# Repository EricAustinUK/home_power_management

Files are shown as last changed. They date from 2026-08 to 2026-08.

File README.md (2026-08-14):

# Home Power Management

A bespoke home power management system built on a Raspberry Pi Zero W, optimised by edge AI and written in Rust.
Predicts solar generation with an on-device ML model, then calculates and schedules battery and EV charging around a cheap energy tariff window via Home Assistant. 

## How it works

- **Solar prediction (`ml/`)**: a compact regression model trained on historical weather and solar pv generation data predicts the next 24 hours of solar output. Inference runs locally on the Pi Zero W (ARMv6, 512 MB RAM).
- **Weather input(`software/home_manager/weather_data.rs`)**: hourly forecasts from the OpenMeteo API feed the model.
- **Battery scheduling**: during tariff windows, the expected house load is compared against predicted solar, the battery is configured to charge to cover any shortfall, then reset to its baseline when the tariff ends.
- **EV conditional charging**: reads an EV's battery level, home location, and plug state from Home Assistant to control an IoT enabled charger, switching it off once the target charge (currently 95%) is reached.
- **Control panel (`control_panel.rs`)**: a physical panel (currently on a breadboard) with three "appliance" toggle switches (though only one of these is currently configured, being the one representing the home being inhabited) that feed into the estimate for home energy consumption. Shows the state for each these appliances with an LED. 

## Optimization for ARM

The model and inference path were developed with the Pi Zero W's hardware limitations in mind.

| Metric | Value |
|---|---|
| Model size on disk | 282B |
| Model data size on disk | 99KB |
| Inference latency (Pi Zero W) | 1.51ms |
| RAM footprint | 3664KB |

## Hardware

- Raspberry Pi Zero W
- Custom control panel housing 3 push switches with pull-ups, status LEDs
- Home Assistant instance with battery, EV, and charger integrations

## Setup

1. Clone and copy `.env.example` to `.env`, filling in:
   - `HASS_IP`, `HASS_PORT`, `HASS_TOKEN` (long-lived access token obtained in Home Assistant developer settings)
   - `BATTERY_NAME`, `EV_NAME`, `EV_CHARGER_NAME` - entity prefixes as they appear in Home Assistant. Current implementation is for an Ecoflow battery, a BYD EV and a VOLDT charger connected to SmartLife; using [hass-byd-vehicle](https://github.com/jkaberg/hass-byd-vehicle), [hassio-ecoflow-cloud](https://github.com/tolwi/hassio-ecoflow-cloud), HomeAssistant's official Tuya SmartLife integration
   - `WEATHER_API_URL`, `PANEL_LATITUDE`, `PANEL_LONGITUDE` - for the weather forecast and history. Currently only OpenMeteo is supported
   - `MODEL_FILENAME`, `MODEL_DATA_FILENAME` - trained model binary if training off the target is preferred (see `ml/`)
2. Cross-compile for the Pi Zero W:
   ```bash
   cd software
   cargo build --target arm-unknown-linux-musleabihf --release
   ```
   (requires the `arm-linux-gnueabihf-gcc` linker)
3. Deploy and run (uses `PI_USER` and `PI_HOST` from `.env`):
   ```bash
   set -a && source ../.env && set +a
   scp target/arm-unknown-linux-musleabihf/release/home_assist $PI_USER@$PI_HOST:~/
   ssh $PI_USER@$PI_HOST "chmod +x ~/home_assist && ~/home_assist"
   ```
   (also available as the "deploy to pi" / "run on pi" tasks in `.vscode/tasks.json`)

## License

MIT, see [LICENSE](LICENSE)

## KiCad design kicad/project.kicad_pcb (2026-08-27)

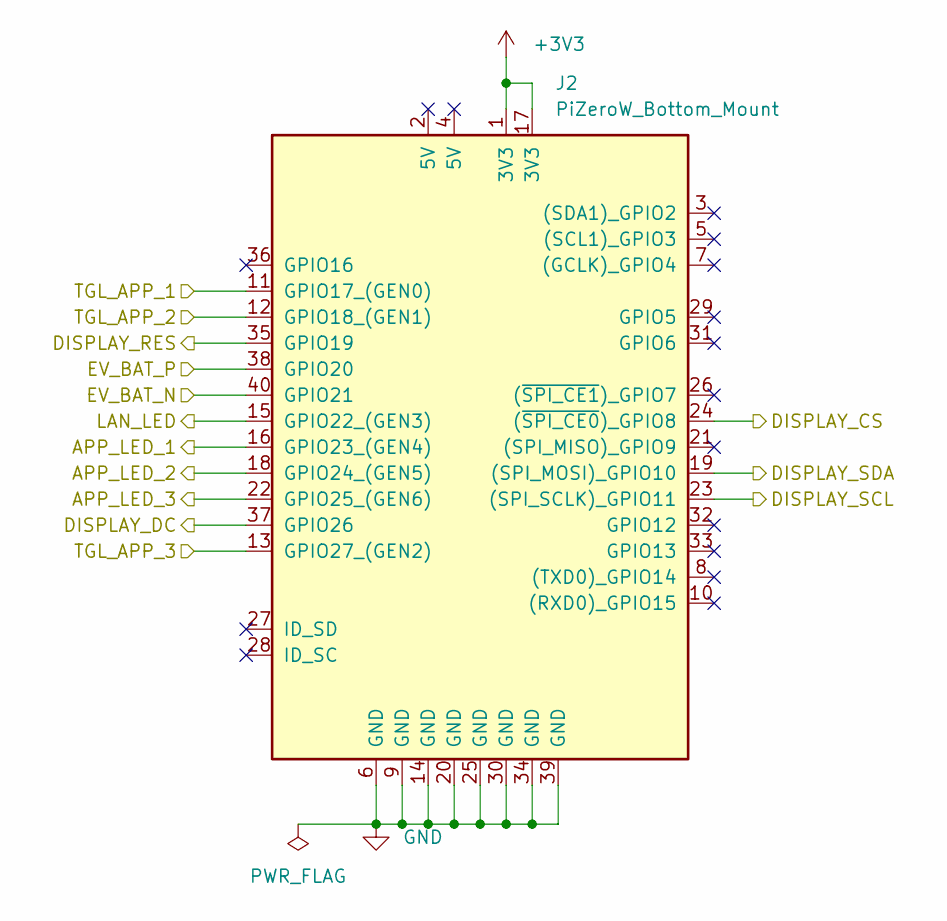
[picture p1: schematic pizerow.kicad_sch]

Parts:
J2: PiZeroW_Bottom_Mount; PinHeader_2x20_P2.54mm_Vertical

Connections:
+3V3: J2.1 (3V3), J2.17 (3V3); also elsewhere on the board
/Control_Panel/EV_BAT_N: J2.40 (GPIO21); also elsewhere on the board
/Control_Panel/EV_BAT_P: J2.38 (GPIO20); also elsewhere on the board
/Control_Panel/TGL_APP_1: J2.11 (GPIO17_(GEN0)); also elsewhere on the board
/Control_Panel/TGL_APP_2: J2.12 (GPIO18_(GEN1)); also elsewhere on the board
/Control_Panel/TGL_APP_3: J2.13 (GPIO27_(GEN2)); also elsewhere on the board
/LCD_Display/LCD_CS: J2.24 ((~SPI_CE0)_GPIO8); also elsewhere on the board
/LCD_Display/LCD_DC: J2.37 (GPIO26); also elsewhere on the board
/LCD_Display/LCD_RES: J2.35 (GPIO19); also elsewhere on the board
/LCD_Display/LCD_SCL: J2.23 ((SPI_SCLK)_GPIO11); also elsewhere on the board
/LCD_Display/LCD_SDA: J2.19 ((SPI_MOSI)_GPIO10); also elsewhere on the board
/LED_Panel/APP_LED_1: J2.16 (GPIO23_(GEN4)); also elsewhere on the board
/LED_Panel/APP_LED_2: J2.18 (GPIO24_(GEN5)); also elsewhere on the board
/LED_Panel/APP_LED_3: J2.22 (GPIO25_(GEN6)); also elsewhere on the board
/LED_Panel/LAN_LED: J2.15 (GPIO22_(GEN3)); also elsewhere on the board
GND: J2.6 (GND), J2.9 (GND), J2.14 (GND), J2.20 (GND), J2.25 (GND), J2.30 (GND), J2.34 (GND), J2.39 (GND); also elsewhere on the board

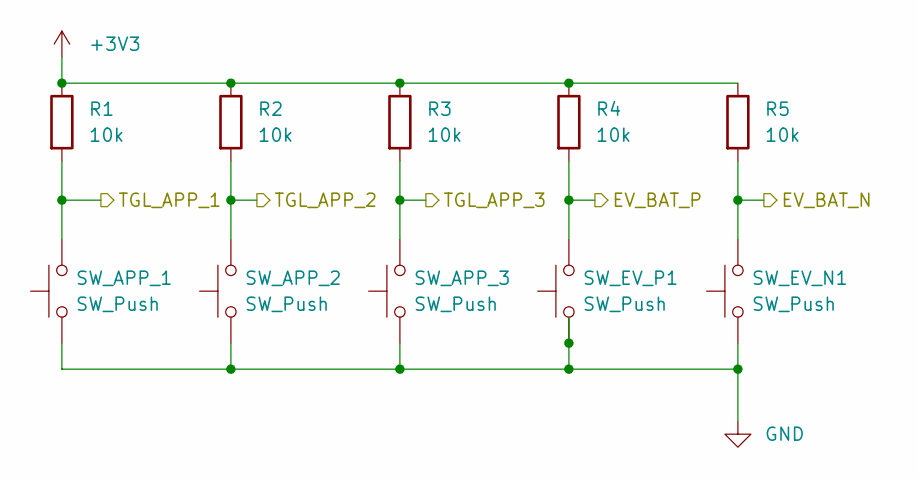
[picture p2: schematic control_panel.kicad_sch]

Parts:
R1, R2, R3, R4, R5: 10k; R_0603_1608Metric
SW_APP_1, SW_APP_2, SW_APP_3: SW_Push; SW_SPST_PTS810
SW_EV_N1: SW_Push; SW_SPST_PTS810
SW_EV_P1: SW_Push; SW_SPST_PTS810

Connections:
+3V3: R1.1, R2.1, R3.1, R4.1, R5.1; also elsewhere on the board
/Control_Panel/EV_BAT_N: R5.2, SW_EV_N1.2; also elsewhere on the board
/Control_Panel/EV_BAT_P: R4.2, SW_EV_P1.2; also elsewhere on the board
/Control_Panel/TGL_APP_1: R1.2, SW_APP_1.2; also elsewhere on the board
/Control_Panel/TGL_APP_2: R2.2, SW_APP_2.2; also elsewhere on the board
/Control_Panel/TGL_APP_3: R3.2, SW_APP_3.2; also elsewhere on the board
GND: SW_APP_1.1, SW_APP_2.1, SW_APP_3.1, SW_EV_N1.1, SW_EV_P1.1; also elsewhere on the board

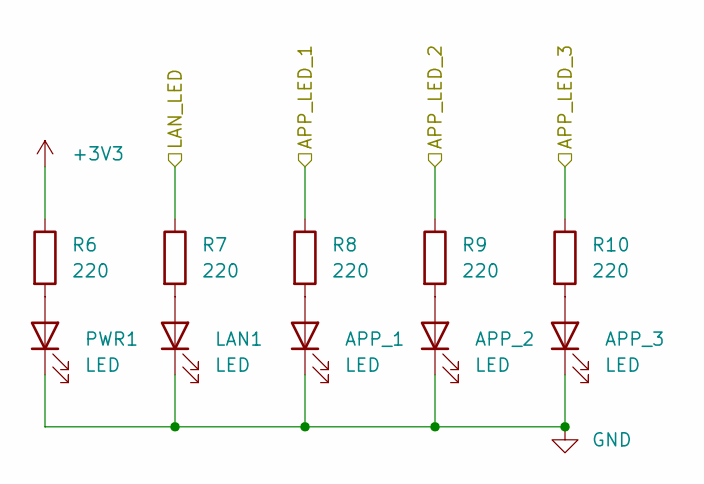
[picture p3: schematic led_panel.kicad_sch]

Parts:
APP_1, APP_2, APP_3: LED; LED_0805_2012Metric
LAN1: LED; LED_0805_2012Metric
PWR1: LED; LED_0805_2012Metric
R6, R7, R8, R9, R10: 220; R_0603_1608Metric

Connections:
+3V3: R6.1; also elsewhere on the board
/LED_Panel/APP_LED_1: R8.1; also elsewhere on the board
/LED_Panel/APP_LED_2: R9.1; also elsewhere on the board
/LED_Panel/APP_LED_3: R10.1; also elsewhere on the board
/LED_Panel/LAN_LED: R7.1; also elsewhere on the board
GND: APP_1.1 (K), APP_2.1 (K), APP_3.1 (K), LAN1.1 (K), PWR1.1 (K); also elsewhere on the board
unnamed: APP_1.2 (A), R8.2
unnamed: APP_2.2 (A), R9.2
unnamed: APP_3.2 (A), R10.2
unnamed: LAN1.2 (A), R7.2
unnamed: PWR1.2 (A), R6.2

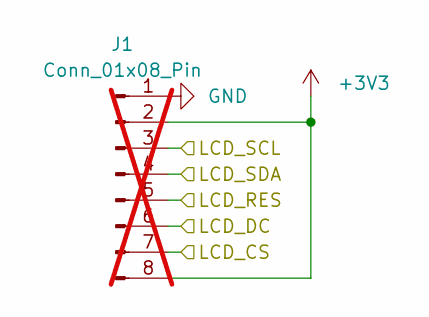
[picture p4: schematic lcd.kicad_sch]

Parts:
J1: Conn_01x08_Pin; PinHeader_1x08_P2.54mm_Vertical; not fitted

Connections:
+3V3: J1.2, J1.8; also elsewhere on the board
/LCD_Display/LCD_CS: J1.7; also elsewhere on the board
/LCD_Display/LCD_DC: J1.6; also elsewhere on the board
/LCD_Display/LCD_RES: J1.5; also elsewhere on the board
/LCD_Display/LCD_SCL: J1.3; also elsewhere on the board
/LCD_Display/LCD_SDA: J1.4; also elsewhere on the board
GND: J1.1; also elsewhere on the board

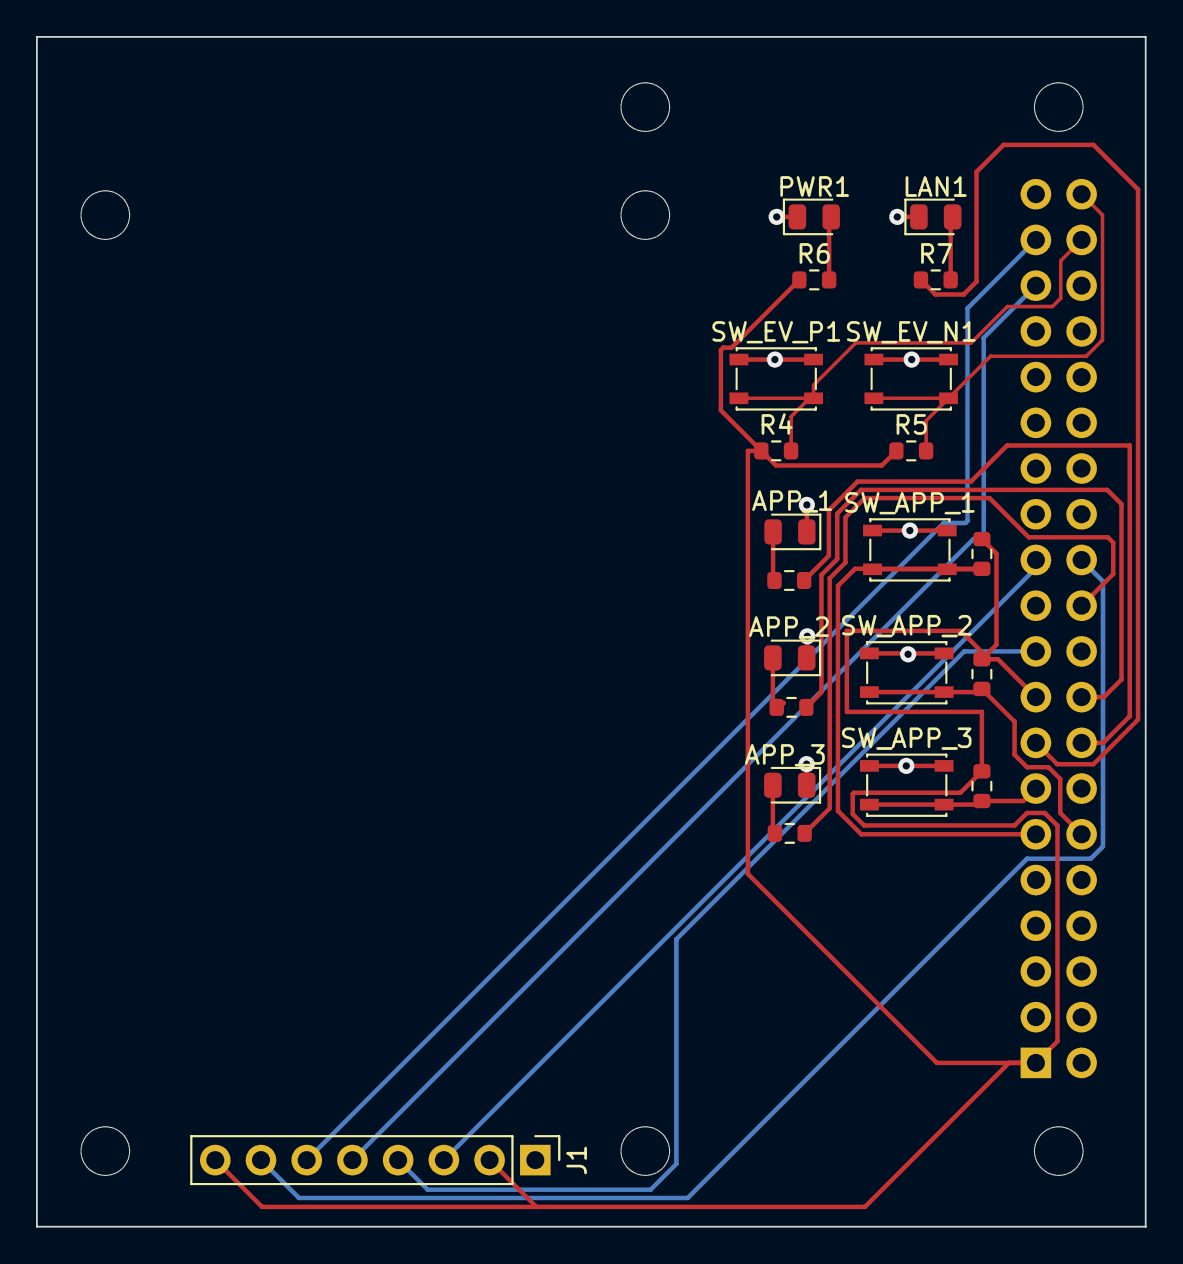
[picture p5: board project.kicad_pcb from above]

Board: 2 copper layers, 61.6 x 66.1 mm, 29 parts (1 on the bottom side), 21 nets.

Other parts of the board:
H1, H2, H3, H4/7, H5, H6, H8: MountingHole_2.7mm_M2.5

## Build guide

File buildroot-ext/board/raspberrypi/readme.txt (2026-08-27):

Raspberry Pi

Intro
=====

These instructions apply to all models of the Raspberry Pi:
  - the original models A and B,
  - the "enhanced" models A+ and B+,
  - the model CM (aka Raspberry Pi Compute Module).
  - the model Zero (aka Raspberry Pi Zero)
  - the model Zero W (aka Raspberry Pi Zero W)
  - the model Zero 2 W (aka Raspberry Pi Zero 2 W)
  - the model B2 (aka Raspberry Pi 2)
  - the model B3 (aka Raspberry Pi 3).
  - the model CM3 (aka Raspberry Pi Compute Module 3).
  - the model CM3+ (aka Raspberry Pi Compute Module 3+).
  - the model B4 (aka Raspberry Pi 4).
  - the model 400 (aka Raspberry Pi 400).
  - the model CM4 (aka Raspberry Pi Compute Module 4 and IO Board).
  - the model CM4s (aka Raspberry Pi Compute Module 4s).
  - the model B5 (aka Raspberry Pi 5).
  - the model 500 (aka Raspberry Pi 500).
  - the model CM5 (aka Raspberry Pi Compute Module 5 and IO Board).

How to build it
===============

Configure Buildroot
-------------------

There are several Raspberry Pi defconfig files in Buildroot, one for
each major variant, which you should base your work on:

For models A, B, A+, B+ and CM:

  $ make raspberrypi_defconfig

For model Zero (model A+ in smaller form factor):

  $ make raspberrypi0_defconfig

or for model Zero W (model Zero with wireless LAN and Bluetooth):

  $ make raspberrypi0w_defconfig

For model Zero 2 W (model B3 in smaller form factor):

  $ make raspberrypizero2w_defconfig

or for model Zero 2 W (model B3 in smaller form factor, 64-bit):

  $ make raspberrypizero2w_64_defconfig

For model 2 B:

  $ make raspberrypi2_defconfig

or for model 2 B (Rev 1.2, model B3 without wireless LAN and Bluetooth, 64 bit):

  $ make raspberrypi2_64_defconfig

For model 3 B, B+, CM3 and CM3+:

  $ make raspberrypi3_defconfig

or for model 3 B, B+, CM3 and CM3+ (64 bit):

  $ make raspberrypi3_64_defconfig

For model 4 B, 400, CM4 and CM4s:

  $ make raspberrypi4_defconfig

or for model 4 B, 400, CM4 and CM4s (64 bit):

  $ make raspberrypi4_64_defconfig

For model CM4 (on IO Board):

  $ make raspberrypicm4io_defconfig

or for CM4 (on IO Board - 64 bit):

  $ make raspberrypicm4io_64_defconfig

For model 5 B and 500:

  $ make raspberrypi5_defconfig

For model CM5 (on IO Board):

  $ make raspberrypicm5io_defconfig

Build the rootfs
----------------

Note: you will need to have access to the network, since Buildroot will
download the packages' sources.

You may now build your rootfs with:

  $ make

(This may take a while, consider getting yourself a coffee ;-) )

Result of the build
-------------------

After building, you should obtain this tree:

    output/images/
    +-- bcm2708-rpi-b-rev1.dtb      [1]
    +-- bcm2708-rpi-b.dtb           [1]
    +-- bcm2708-rpi-b-plus.dtb      [1]
    +-- bcm2708-rpi-cm.dtb          [1]
    +-- bcm2708-rpi-zero.dtb        [1]
    +-- bcm2708-rpi-zero-w.dtb      [1]
    +-- bcm2709-rpi-2-b.dtb         [1]
    +-- bcm2710-rpi-2-b.dtb         [1]
    +-- bcm2710-rpi-3-b.dtb         [1]
    +-- bcm2710-rpi-3-b-plus.dtb    [1]
    +-- bcm2710-rpi-cm3.dtb         [1]
    +-- bcm2710-rpi-zero-2-w.dtb    [1]
    +-- bcm2711-rpi-4-b.dtb         [1]
    +-- bcm2711-rpi-400.dtb         [1]
    +-- bcm2711-rpi-cm4.dtb         [1]
    +-- bcm2711-rpi-cm4s.dtb        [1]
    +-- bcm2712-rpi-5-b.dtb         [1]
    +-- bcm2712d0-rpi-5-b.dtb       [1]
    +-- bcm2712-rpi-500.dtb         [1]
    +-- bcm2712-rpi-cm5-cm5io       [1]
    +-- bcm2712-rpi-cm5l-cm5io      [1]
    +-- boot.vfat
    +-- rootfs.ext4
    +-- rpi-firmware/
    |   +-- bootcode.bin            [2]
    |   +-- cmdline.txt
    |   +-- config.txt
    |   +-- fixup.dat               [3]
    |   +-- fixup4.dat              [4]
    |   +-- start.elf               [3]
    |   +-- start4.elf              [4]
    |   `-- overlays/               [5]
    +-- sdcard.img
    +-- Image                       [1]
    `-- zImage                      [1]

[1] Not all of them will be present, depending on the RaspberryPi
    model you are using.

[2] Only for the Raspberry Pi 1, 2, 3, Zero, Zero W and Zero 2 W. The Raspberry
    Pi 4, 400, 5 and the Compute Module 4, 4s and 5 load the second stage
    bootloader from a SPI flash EEPROM.

[3] Only for the Raspberry Pi 1, 2, 3, Zero and Zero 2.

[4] Only for the Raspberry Pi 4, 400, Compute Module 4 and 4s.

[5] Only for the Raspberry Pi installing device-tree overlays. The Raspberry Pi
    with Bluetooth connectivity (Zero W, Zero 2 W, 3, 4, 400, Compute Module 4
    and 4s) use the miniuart-bt overlay to enable UART0 for the serial console;
    the Bluetooth uses the mini-UART instead. Alternative would be to disable
    the serial console in cmdline.txt and /etc/inittab.

How to write the SD card
========================

Once the build process is finished you will have an image called "sdcard.img"
in the output/images/ directory.

Copy the bootable "sdcard.img" onto an SD card with "dd":

  $ sudo dd if=output/images/sdcard.img of=/dev/sdX

Insert the SDcard into your Raspberry Pi, and power it up. Your new system
should come up now and start two consoles: one on the serial port on
the P1 header, one on the HDMI output where you can login using a USB
keyboard.

How to write to CM4 eMMC memory
===============================

For CM4 modules without eMMC memory see above for booting from SD card,
for CM4 modules with eMMC memory proceed as following:

- fit jumper on IO Board header J2 to disable eMMC boot
- connect IO Board micro USB port (J11 USB slave) to your host linux system
- power up CM4/IO Board (lsusb command should show a '0a5c:2711 Broadcom Corp.
  BCM2711 Boot' device)
- run 'sudo ./host/bin/rpiboot', output should look like the following:
    Waiting for BCM2835/6/7/2711...
    Loading embedded: bootcode4.bin
    Sending bootcode.bin
    Successful read 4 bytes
    Waiting for BCM2835/6/7/2711...
    Loading embedded: bootcode4.bin
    Second stage boot server
    Loading embedded: start4.elf
    File read: start4.elf
    Second stage boot server done

- a USB mass storage device should show up (the CM4 eMMC memory), proceed
  as described above to copy sdcard.img to it
- power down CM4/IO Board
- remove jumper on IO Board header J2 to re-enable eMMC boot
- power up CM4/IO Board

CM5 debug UART
==============

The debug UART header is not assembled on the Compute Module 5.

	2.23. Debug UART

	Space is provided for the user to fit a debug UART connector. This
	connector provides the same functionality as Raspberry Pi 5. The
	connector is a three-pin 1mm pitch JST-SH connector, Part number
	BM03B-SRSS-TB. The signals are replicated on the bottom as test points.

	Appendix B: Test Points

	| Reference | X   | Y    | NAME          |
	| TP35      | 11  | 37.8 | DEBUG_UART_TX |
	| TP36      | 8.5 | 37.1 | DEBUG_UART_RX |

	Debug UART

	TP35 and TP36 are a TX and RX of the debug UART. TP46 should be used as
	the ground. It is very useful to have access to these pins during
	programming and initial boot.

See https://datasheets.raspberrypi.com/cm5/cm5-datasheet.pdf.

The signals are not wired up to 100-pin headers either. And thus, it is
impossible to output early boot traces in the EEPROM firmware without
assembling a JST-SH connector (or using the test points).

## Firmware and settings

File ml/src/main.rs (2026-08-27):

mod rill_structs;
use std::path::Path;

use linfa_elasticnet::ElasticNet;
use rill_structs::*;
use ndarray::{Axis, Array1, Array2, s};
use linfa::prelude::*;

use csv::ReaderBuilder;

fn load_x(path: &str) -> Array2<f64> {
    let mut rdr = ReaderBuilder::new()
        .has_headers(true)
        .from_path(path)
        .unwrap();

    let rows: Vec<Vec<f64>> = rdr
        .records()
        .map(|r| {
            let record = r.unwrap();

            // Skip time column, parse remaining 9 columns
            record
                .iter()
                .skip(1)
                .map(|v| v.parse::<f64>().unwrap())
                .collect()
        })
        .collect();

    let nrows = rows.len();
    let ncols = rows[0].len();

    let flat: Vec<f64> = rows.into_iter().flatten().collect();

    Array2::from_shape_vec((nrows, ncols), flat).unwrap()
}

fn load_y(path: &str) -> Array1<f64> {
    let mut rdr = ReaderBuilder::new()
        .has_headers(true)
        .from_path(path)
        .unwrap();

    let values: Vec<f64> = rdr
        .records()
        .map(|r| {
            let record = r.unwrap();
            record[1].parse::<f64>().unwrap()
        })
        .collect();

    Array1::from_vec(values)
}

fn main() {
    println!("{}", std::env::current_dir().unwrap().display());
    let x = load_x("data/weather_features.csv");
    let y = load_y("data/power_generation.csv");

    let mean = x.mean_axis(Axis(0)).unwrap();
    let var = x.var_axis(Axis(0), 0.0);
    let s_dev = var.mapv(|v:f64| v.sqrt());

    let mut x_scaled = x.clone();
    for mut row in x_scaled.rows_mut() {
        row -= &mean;
        row /= &s_dev;
    }

    let dataset = Dataset::new(x_scaled, y.clone());

    let reg_model = ElasticNet::params()
        .l1_ratio(0.)
        .penalty(500.)
        .fit(&dataset)
        .unwrap();

    let weights = reg_model.hyperplane().to_vec();
    let intercept = reg_model.intercept();

    let feature_count = 9;
    let samples_seen = x.nrows() as u64;

    let m2s: Vec<f64> = var.iter()
        .map(|&v| v * (samples_seen as f64 - 1.0))
        .collect();

    let stored_model = MockRegressionPipeline {
        transformer: MockStandardScaler {
            feature_count,
            config: MockStandardScalerConfig {
                with_mean: true,
                with_std: true,
                epsilon: 1e-12,
            },
            counts: vec![samples_seen; feature_count],
            means: mean.to_vec(),
            m2s,
        },
        model: MockLinearRegression {
            feature_count,
            weights: weights,
            intercept: intercept,
            optimizer: MockOptimizer::Sgd(MockSgd {
                feature_count,
                config: MockSgdConfig {
                    learning_rate: 0.001,
                    l2: 0.001,
                },
                samples_seen,
            }),
            loss: MockRegressionLoss::SquaredError,
            samples_seen,
        },
    };

    let stored_snapshot = SnapshotMirror {
        format_version: 1,
        model: stored_model
    };

    let model_path = Path::new("output/model.bin");

    std::fs::create_dir_all(model_path.parent().unwrap()).unwrap();
    std::fs::write(model_path, postcard::to_allocvec(&stored_snapshot).unwrap()).unwrap();
    println!("Model saved successfully");

    let samples = x.nrows();

    let mut training_data = Array2::<f64>::zeros((samples, 10));

    training_data
        .slice_mut(s![.., 0..9])
        .assign(&x);

    training_data
        .column_mut(9)
        .assign(&y);

    let training_data_vec: Vec<[f64; 10]> = training_data
        .outer_iter()
        .map(|row| row.to_vec().try_into().unwrap())
        .collect();
    
    let bytes = postcard::to_allocvec(&training_data_vec).unwrap();

    std::fs::write(
        "output/model_data.bin",
        bytes
    ).unwrap();


}

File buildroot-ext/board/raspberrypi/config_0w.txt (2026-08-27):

# Please note that this is only a sample, we recommend you to change it to fit
# your needs.
# You should override this file using BR2_PACKAGE_RPI_FIRMWARE_CONFIG_FILE.
# See http://buildroot.org/manual.html#rootfs-custom
# and http://elinux.org/RPiconfig for a description of config.txt syntax

start_file=start.elf
fixup_file=fixup.dat

kernel=zImage
dtparam=spi=on

# To use an external initramfs file
#initramfs rootfs.cpio.gz

# Disable overscan assuming the display supports displaying the full resolution
# If the text shown on the screen disappears off the edge, comment this out
disable_overscan=1

# How much memory in MB to assign to the GPU on Pi models having
# 256, 512 or 1024 MB total memory
gpu_mem_256=100
gpu_mem_512=100
gpu_mem_1024=100

# Enable UART0 for serial console on ttyAMA0
dtoverlay=miniuart-bt

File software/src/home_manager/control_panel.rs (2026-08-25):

use std::{sync::mpsc::Sender, time::Duration};
use rppal::gpio::{Gpio, InputPin, Level, OutputPin, Trigger};

pub struct PanelState {
    pub app_1: bool,
    pub app_2: bool,
    pub app_3: bool,
    lan: bool, 
    leds: [OutputPin; 4],
    pub ev_target_perc:u8,
    _tgl_pins: Vec<InputPin>
}

impl PanelState{
    pub fn new (tx:&Sender<u8>) -> Result<Self, rppal::gpio::Error>{
        let gpio = Gpio::new()?;
        let leds = Self::init_leds(&gpio)?;
        
        let tgl_pins: Vec<InputPin> = [17, 18, 27, 20, 21]
            .into_iter()
            .map(|pin_no| {
                let mut pin = gpio.get(pin_no)?.into_input_pullup();
                let pin_no = pin.pin();
                let btn_tx = tx.clone();

                pin.set_async_interrupt(
                    Trigger::RisingEdge,
                    Some(Duration::from_millis(50)),
                    move |_| {
                        match btn_tx.send(pin_no){
                            Ok(_) => (),
                            Err(e) => println!("Error sending GPIO signal to channel for event: {:?}", e) // TODO: add retry
                        }
                    },
                )?;

                Ok(pin) 
            })
            .collect::<Result<Vec<InputPin>, rppal::gpio::Error>>()?;

        
        Ok(Self { app_1:false, app_2:false, app_3:false, lan:false, leds:leds, ev_target_perc:95, _tgl_pins:tgl_pins })
    }

    pub fn handle_pin(&mut self, pin:u8){
        let (on, ind) = match pin {
            17 => (&mut self.app_1, 0),
            18 => (&mut self.app_2, 1),
            27 => (&mut self.app_3, 2),
            // ev_charge
            20 => { self.ev_target_perc = (self.ev_target_perc + 5).min(95); return },
            21 => { self.ev_target_perc = (self.ev_target_perc - 5).max(25); return },
            _ => return,
        };

        *on = !*on;

        self.leds[ind].write(if *on {Level::High} else {Level::Low});
    }

    pub fn set_lan(&mut self, on:bool){
        self.lan = on;
        self.leds[3].write(if on {Level::High} else {Level::Low});
    }

    pub fn init_leds(gpio:&Gpio) -> Result<[OutputPin; 4], rppal::gpio::Error> {
        let led_app1 = gpio.get(23)?.into_output();
        let led_app2 = gpio.get(24) ?.into_output();
        let led_app3 = gpio.get(25)?.into_output();
        let led_lan = gpio.get(22)?.into_output();

        Ok([led_app1, led_app2, led_app3, led_lan])
    }

}

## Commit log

2026-08-05 completed desired LED state machine for enabling and disabling appliances. TODO: proper error handling, currently unwraps everywhere + some kind of in-os state where it will save a file with the stat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
    [main.rs]
2026-08-05 fixed gitignore on kicad
2026-08-06 added stubs for classes which between them control the IoT devices
2026-08-09 significant changes to error handling and removal of some more unused imports
    [control_panel.rs, main.rs, mod.rs]
2026-08-09 big changes: replaced reqwest with ureq (basically does the same thing but doesn't need a heavy async runtime), and used this to implement weather data, which works for now on the pi. Still needs som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
    [main.rs]
2026-08-10 overhaul of error checking system + stubs for training + inference in homemanager
    [main.rs, mod.rs]
2026-08-10 mutablility fix to homemanager train step
    [mod.rs]
2026-08-10 added logic for loading MLEngine with a pre-baked model (could be used for restoring after power loss too)
2026-08-13 changed logic of interrupt handling to (sort of) work on a single thread and removed redundant mutex + arc logic
2026-08-13 fixes to solar pv value fetching
    [main.rs, mod.rs]
2026-08-13 switched ev + charger to being home assistant devices as I managed to integrate them
2026-08-13 fully removed caching to reduce complication, home assistant caches these values anyway so I don't have to spam poll the device itself
2026-08-13 Implemented SoC fetch methods for EV and battery
2026-08-14 implemented (untested) method for updating the battery SoC
2026-08-14 removed most redundant imports and fixed some of the device names
    [control_panel.rs, mod.rs]
2026-08-14 completed implementation of EV conditional charging (BDY app allows management of the time to charge). Variable resistor hasn't been brought up yet but leaving it at the hardcoded 95% value for now
2026-08-14 minor bug and typo fixes
    [main.rs, mod.rs]
2026-08-14 last min bugfix!!! device name was wrong for battery min level update
2026-08-25 developed proper schematic in KiCad along with supporting firmware. code still doesnt gracefully handle all errors but it now does for ureq (network) errors, turning the LAN light off but not ejecting
    [control_panel.kicad_sch, lcd.kicad_sch, led_panel.kicad_sch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]
2026-08-27 added custm raspberry pi config to buildroot ext (in order to add display over SPI) and display config
    [config_0w.txt, config_2_64bit.txt, config_3.txt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]
2026-08-27 adjustments to design on kicad
    [control_panel.kicad_sch, lcd.kicad_sch, led_panel.kicad_sch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]
2026-08-27 completed board layout and passed drc
    [control_panel.kicad_sch, lcd.kicad_sch, led_panel.kicad_sch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]
2026-08-27 routed pcb, only bom left to do
    [control_panel.kicad_sch, lcd.kicad_sch, led_panel.kicad_sch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]
2026-08-28 Display + ev controls now working dynamically with buttons (currently using dummy home manager data). UI needs work to make SoC limit look better.
2026-09-10 kicad changes
    [control_panel.kicad_sch, led_panel.kicad_sch, pizerow.kicad_sch]
